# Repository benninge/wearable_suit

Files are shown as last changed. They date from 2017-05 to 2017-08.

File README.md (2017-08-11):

# Smart dancing suit

The smart dancing suit project was part of the [Wearable Computing Systems Lab Course](https://es.informatik.uni-freiburg.de/teaching/wearable-lab) during the summer semester of 2017. The idea is to develop an LED covered dancing suit which generates a light show according to the current music and movements of the wearer, instead of running a predefined choreography like it is done in other approaches. This is what makes the suit a “smart" dancing suit.

Therefore the suit is equipped with a couple of sensors, which enable sensing of motions and sound. For the sound measurement, a microphone module is used. The measurement samples are then used to calculate the sound level or to apply a Fourier transform. The music spectrum can be shown on the chest display.
The motion measurements are performed by inertial measurement units (IMUs) which are mounted on hands and feet. This allows movement detection of individual body parts.

## Contents

* [System architecture](https://github.com/benninge/wearable_suit/blob/master/README.md#hardware-architecture)
    * [Mainboard](https://github.com/benninge/wearable_suit/blob/master/README.md#mainboard)
    * [Sensor Board](https://github.com/benninge/wearable_suit/blob/master/README.md#sensor-board)
* [Software](https://github.com/benninge/wearable_suit/blob/master/README.md#software)
    * [Mainboard firmware](https://github.com/benninge/wearable_suit/blob/master/README.md#mainboard-firmware)
    * [Sensor board firmware](https://github.com/benninge/wearable_suit/blob/master/README.md#sensor-board-firmware)
    * [App](https://github.com/benninge/wearable_suit/blob/master/README.md#app)

## Hardware architecture

The system is built according to the hardware architecture given in figure 1. The centerpiece of the system is the mainboard. It contains an STM32 microcontroller, which controls all the other modules. It is connected to the IMU sensor modules over a bus systems and it directly controls all LEDs as well as the microphone module, which is used for music detection. A bluetooth connection to an Android app was also planned, but is currently not implemented.

<figure role="group">
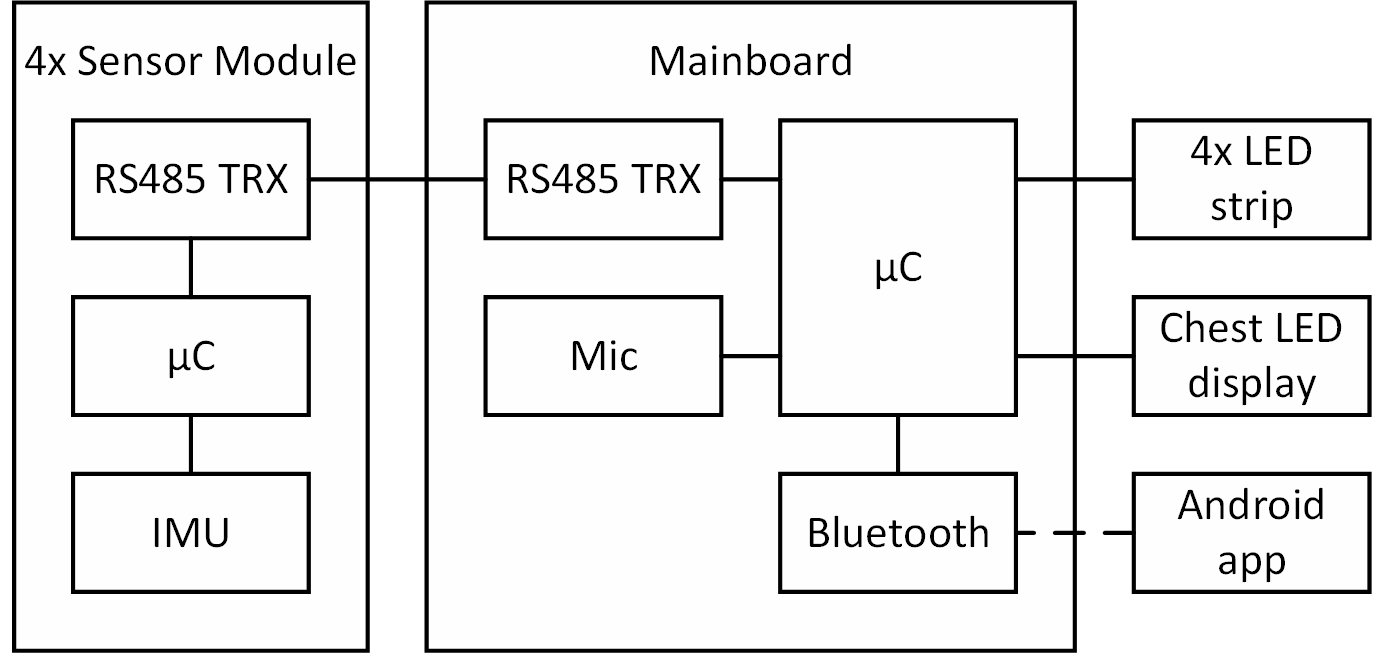
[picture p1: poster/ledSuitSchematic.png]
 
<div align="center"><figcaption> Figure 1: Schematic setup of the system </figcaption></div> 
</figure>

### Mainboard

The mainboard consists of an STM32F411E discovery board with a breadboard shield. The shield powers the discovery board and connects it to the sensor boards, the WS2812 RGB LED strips on arms and legs, the 10 x 10 LED display on the chest and the Adafruit MAX9814 microphone module. A wiring diagram of the mainboard shield is shown in figure 2.

<figure role="group">
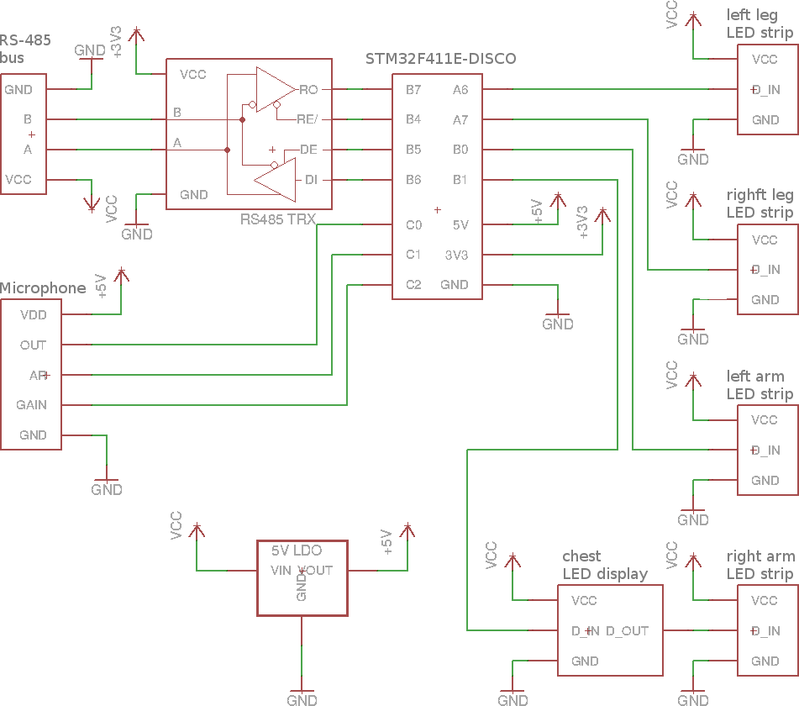
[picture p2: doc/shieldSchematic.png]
 
<div align="center"><figcaption> Figure 2: Wiring diagram of the mainboard shield </figcaption></div> 
</figure>

The sensor boards are connected over an RS-485 based bus system. The RS-485 transceiver should be a model with a 3.3V logic level. The chest display and the LED strips have to be connected according to the defines in the header files WS2812.h, ledSuit.h and the source file ledSuit.c of the mainboard firmware (which may be configured according to the used led-strip lengths). Since the LED strips are powered with 5V, each LED strip uses a switching regulator to generate its supply voltage out of the 3s LiPo power supply (which is called VCC here).

### Sensor board

The sensor module is an Arduino compatible custom circuit board. Figure 3 shows an assembled sensor board. The EAGLE files can be found in the "SensorBoard" folder in this repository. The sensor board hardware uses an ATmega328P microcontroller and a MPU-9250 IMU. It is directly powered by the 3s LiPo power supply and connected to the mainboard over the RS-485 bus.

<figure role="group">
 
<div align="center"><figcaption> Figure 3: Sensor board </figcaption></div> 
</figure>

## Software

This project provides a software development kit for the mainboard containing examples. Additionally, a sensor board firmware is provided as well as an incomplete Android app to control the suit with a smartphone.

### Mainboard firmware

The mainboard firmware can be found in the "mainboard" folder. It contains all libraries for developing your own project as well as some example programs which show the capabilities of the provided libraries.

#### Libraries

The module structure of the mainboard firmware is shown in figure 4. The used hardware modules are colored in blue and the libraries are colored in green. The whole suit functionality can easily be accessed through high level functions, provided by the software development kit libraries. The example program libraries show how the software development kit can be used, to program specific applications.

<figure role="group">
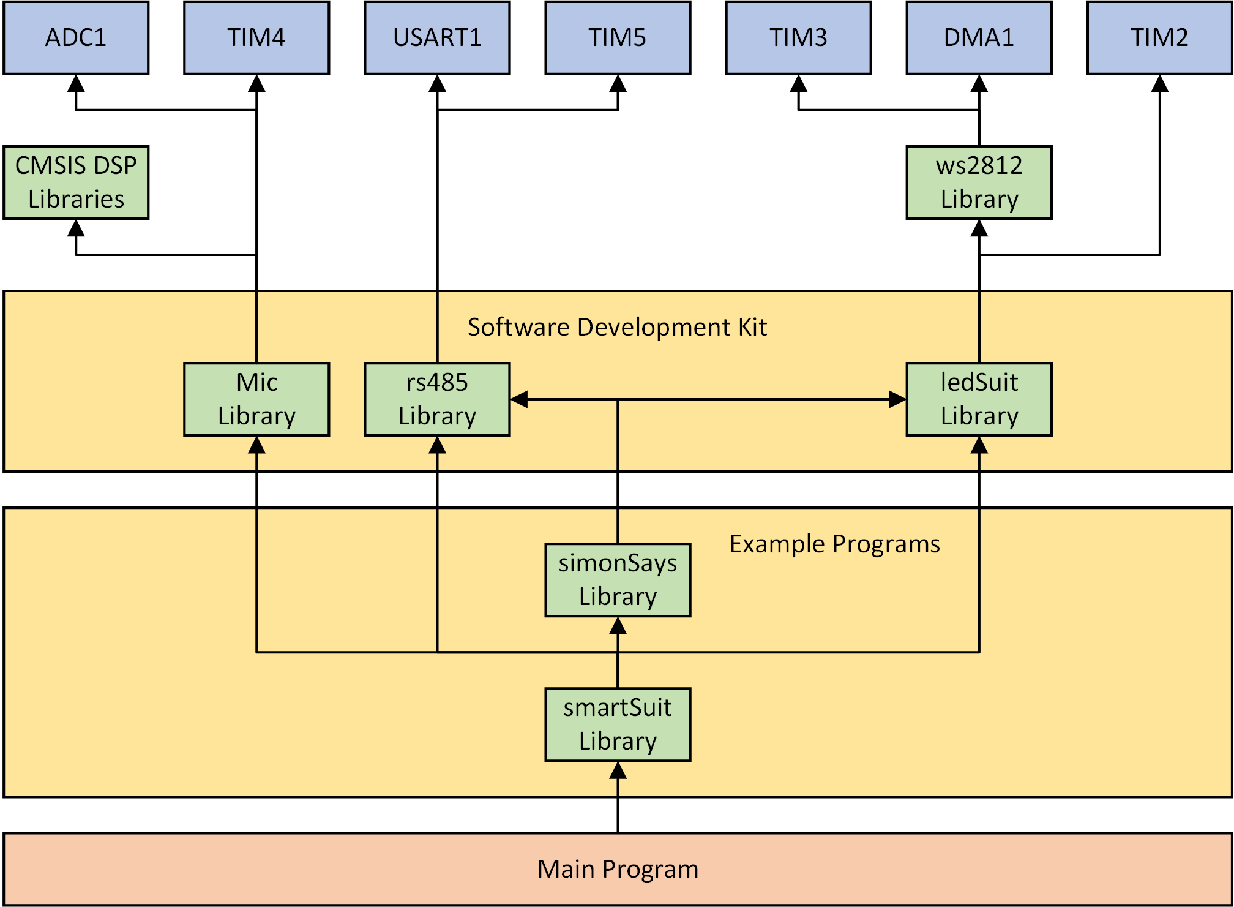
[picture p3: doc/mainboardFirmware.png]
 
<div align="center"><figcaption> Figure 4: Module structure of the mainboard firmware </figcaption></div> 
</figure>

#### Examples

The smartSuit library offers some example programs which show the capabilities of the software development kit. The examples are directly called in the main function and can be chosen by passing a different demo number to the smartSuit_demo function :
```c
void smartSuit_demo(int demoNumber);
```
The following demos are available:

1. Music spectrum and color fade auto rotate demo: Shows the music spectrum on the chest display and an automatically rotating color fade on arms and legs.
2. Sound level and moving demo: Lights up moving body parts with an automatically rotating color fade. The suit brightness depends on the sound level.
3. Music spectrum and strobe moving demo: Shows the music spectrum on the chest display and lights up moving body parts with a strobe.
4. Moving and auto color fade demo: Fades the color of the whole Suit and lights up moving body parts.
5. Pulse and smiley demo: Shows moving pulses on arms and legs and a smiley on the chest display.
6. Play Simon says: An implementation of the game "Simon says". The suit displays body movements, which the wearer has to reproduce.

### Sensor board firmware

Before flashing the firmware to the sensor boards, the Arduino bootloader needs to be flashed to the sensor boards according to the [Arduino ISP instructions](https://www.arduino.cc/en/Tutorial/ArduinoISP). The sensor board firmware can be found in the "arduino/src/mpu9250_basicDMP" folder.

The Digital Motion Processor (DMP) on the IMU of each sensor board performs 6-axis sensor fusion (ignoring the integrated magnetometer and barometer) using the [motion driver library](http://www.digikey.de/en/pdf/i/invensense/motion-driver-6-1-user-guide) of Invensense. The resulting quaternions and acceleration values are transmitted over I^2C to the ATmega328P microcontroller 100 times per second. The microcontroller then converts the quaternions into the Euler coordinate system and normalizes the acceleration values into multiples of g = 9.81 m/s^2. 9-axis fusion is possible using the MPU9250, but would result in a slower update rate and additional need to calibrate the magnetometer each time the suit is powered up.

A master-slave communication over RS485 is used to communicate these values from each sensor board to the mainboard. The master (mainboard) requests new sensor values of one slave (sensor board) at a time. This avoids possible packet collisions on the bus. To differentiate the sensor boards from each other, the SLAVE_ID in mpu9250_basicDMP.ino has to be set to a value between 1 and 4 which represents the sensor boards specific ID. Once a sensor board receives a request for new values, it checks if the request was meant for its SLAVE_ID. If that is the case, it sends back a package with the current yaw, pitch, roll, the current rates at which these values change, and the 3-axis acceleration values.

The following values for SLAVE_ID are used:
* SLAVE_ID = 1: left arm
* SLAVE_ID = 2: right arm
* SLAVE_ID = 3: left leg
* SLAVE_ID = 4: right leg

### App

The "App" folder contains the app source code. The app is programmed with Android Studio and therefore available for Android devices. With the help of the "Dancing Suit" app, the user can select features for the suit. The app runs on a smartphone but cannot connect to the suit yet, because the Bluetooth communication to the mainboard is not fully implemented.

The app starts with a splash screen. From the main activity the user can connect the suit to the Bluetooth module and slide in a navigation drawer. It contains the navigation destinations "Right Arm", "Left Arm", "Right Leg", "Left Leg", "Suit", "Demo", "Info" and "Share". A screenshot of the navigation drawer is shown in figure 5 (left). The user can control each body part separately, set settings for the hole suit, get information about the developer and find the share link for github.

In the activity COLOR, which is shown in figure 5 (middle), the settings for colors can be set. The checkboxes allow the user to select the colors. Furthermore, there are activities for the COLORFADE function and the AUTOCOLORFADE function. To get an overview about the functions and what they do, check out the header file "ledSuit.h" in the mainboard firmware. For each of the three activities, there is a spinner to choose the blinking pattern of the suit. Figure 5 (right) shows the contents in a pop-up dialog.

<figure role="group">
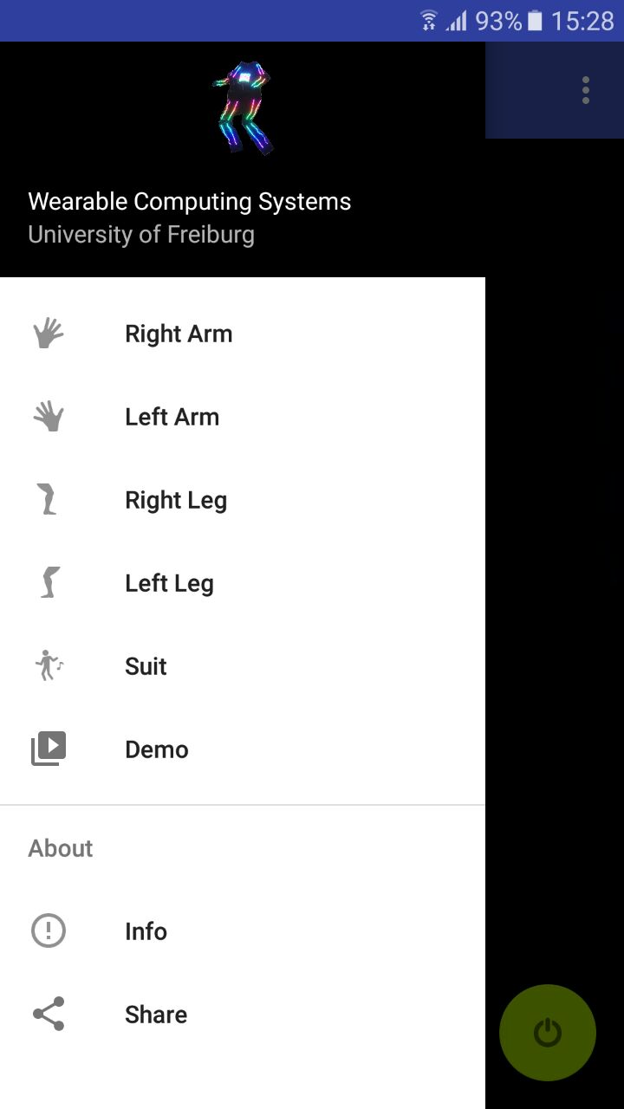
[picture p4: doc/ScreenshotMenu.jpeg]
<div align="center">
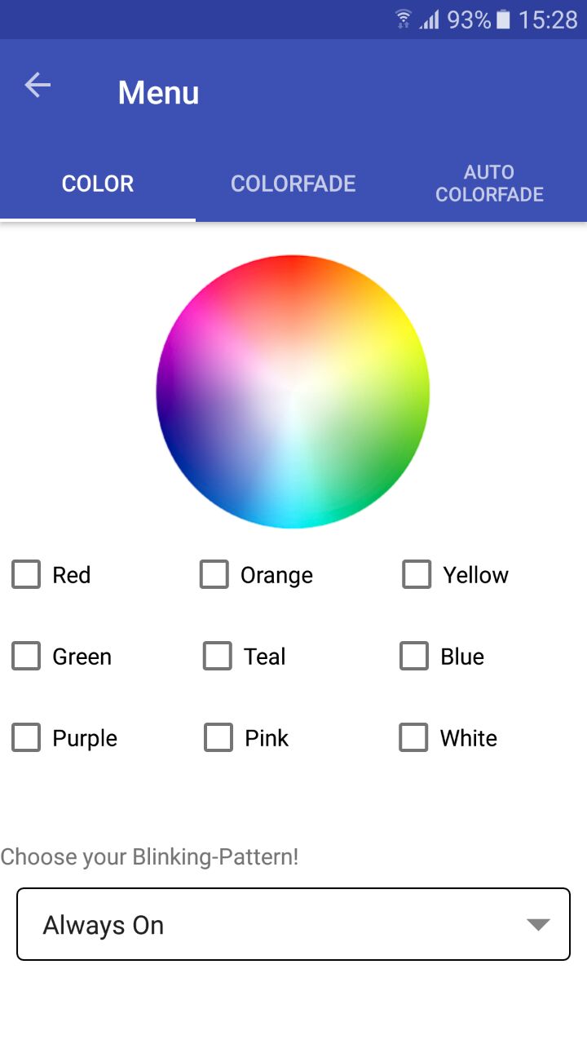
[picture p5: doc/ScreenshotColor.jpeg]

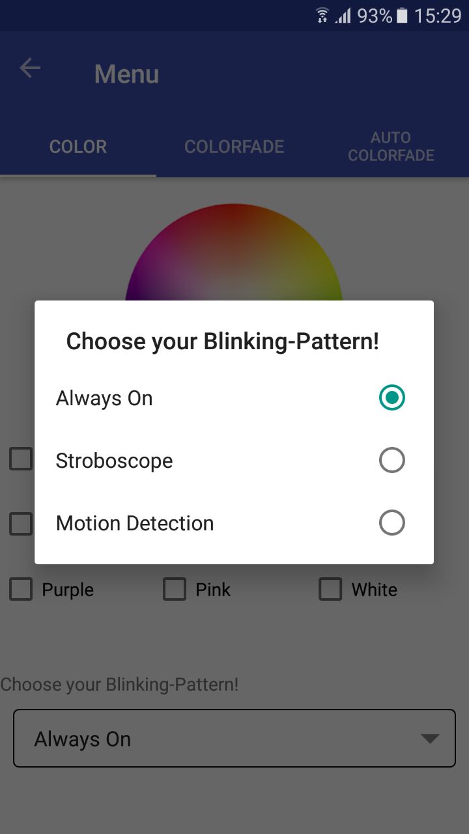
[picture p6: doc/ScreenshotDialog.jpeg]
</div> 
<div align="center"><figcaption> Figure 5: Navigation drawer of the Dancing Suit app (left), activity for color settings (middle) and spinner dialog for blinking pattern (right)</figcaption></div> 
</figure>

To implement the wireless data exchange the Android Bluetooth APIs are used. Following the guide from 
[Android Developers](https://developer.android.com/guide/topics/connectivity/bluetooth.html), scanning for Bluetooth devices and adapting to the module with an insert mac address works but there is no function for data transmission.

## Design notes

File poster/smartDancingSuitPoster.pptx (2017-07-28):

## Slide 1

Smart dancing suit

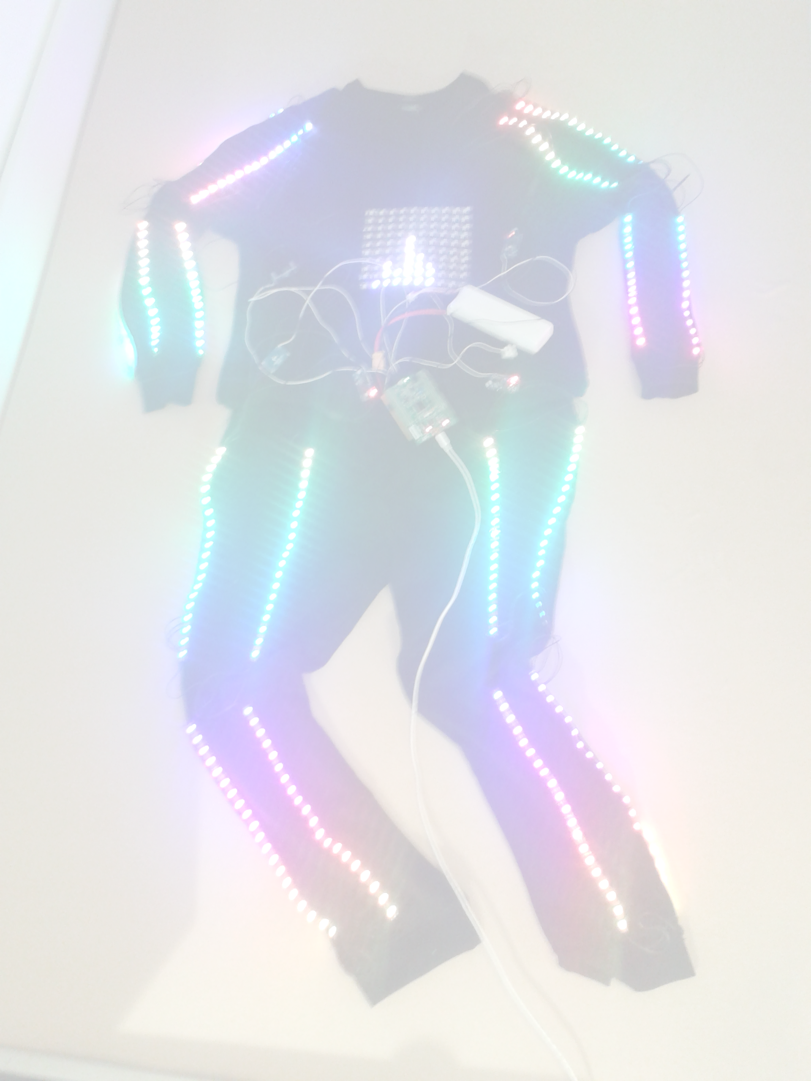
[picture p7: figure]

Making music visible

- The sound of the environment is measured by a microphone
- LEDs react to the environment sound
- Intelligent music recognition by applying fourier transform to the sound measurements
- Displaying of the music spectrum on chest

Reacting to movements

- Body movements are detected by IMUs mounted on hands and feet
- The IMUs perform 6-axis sensor fusion
- LEDs react to the movements measured by the IMUs

Creating an audiovisual performance

- LEDs change their colors and blinking patterns according to the music and the movements of the wearer
- Suit behavior can be configured via android app
- Generating an LED-choreography on the fly

TODO: fancy title

Schematc setup of the system

- Arduino-compatible custom sensor board hardware
- Yaw, pitch, roll and 3-axis acceleration data of each body part gets sent to the mainboard over an RS485 master-slave bus
- STM32F4 discovery board with breadboard shield as mainboard
- Individually addressable WS2812 RGB LEDs
- Sound detection with adafruit MAX9814 microphone module
- Communication with the android app via bluetooth
- TODO: Add some information about bluetooth communication and app

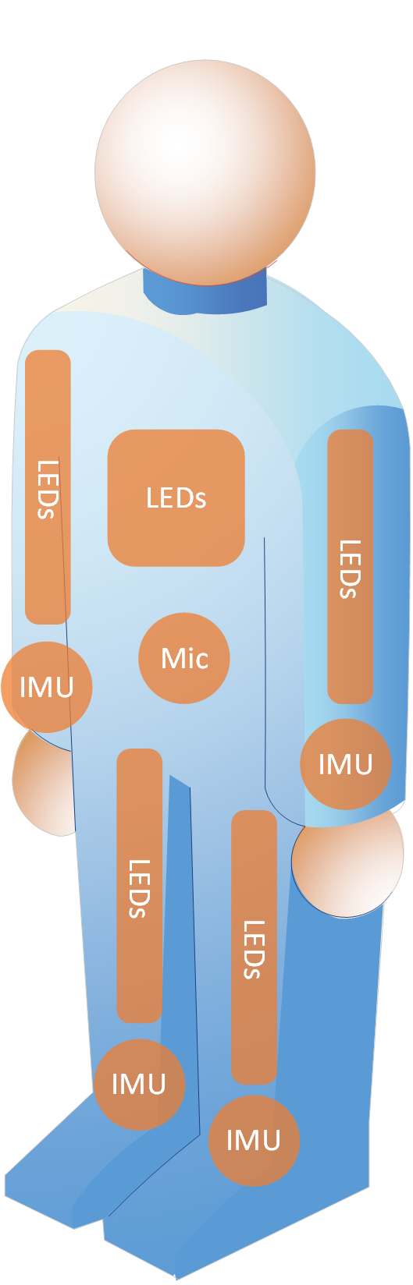
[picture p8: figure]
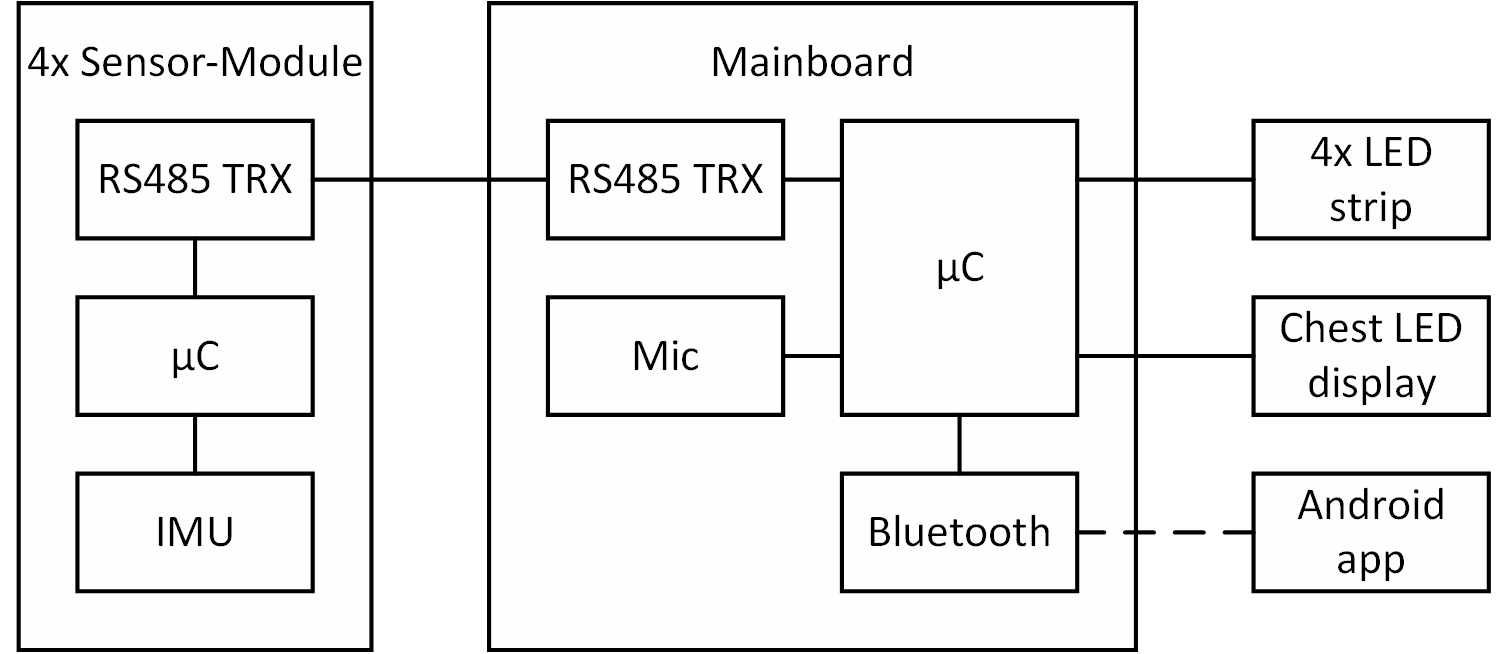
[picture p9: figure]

Positions of the sensors and LEDs on the suit

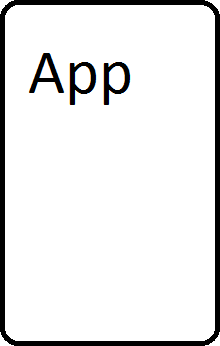
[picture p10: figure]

TODO: nice picture title (and a nice picture)

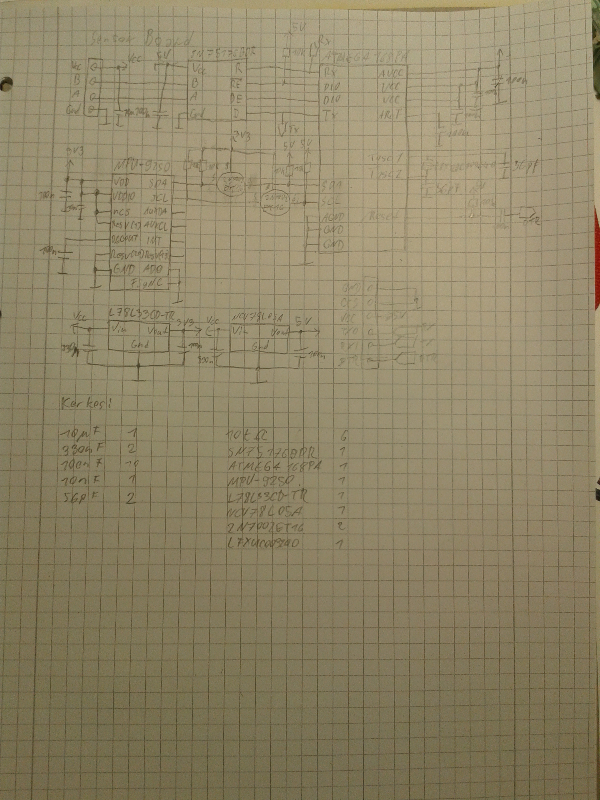
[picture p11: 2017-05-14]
SensorBoard/SensorBoardSchematic.jpg

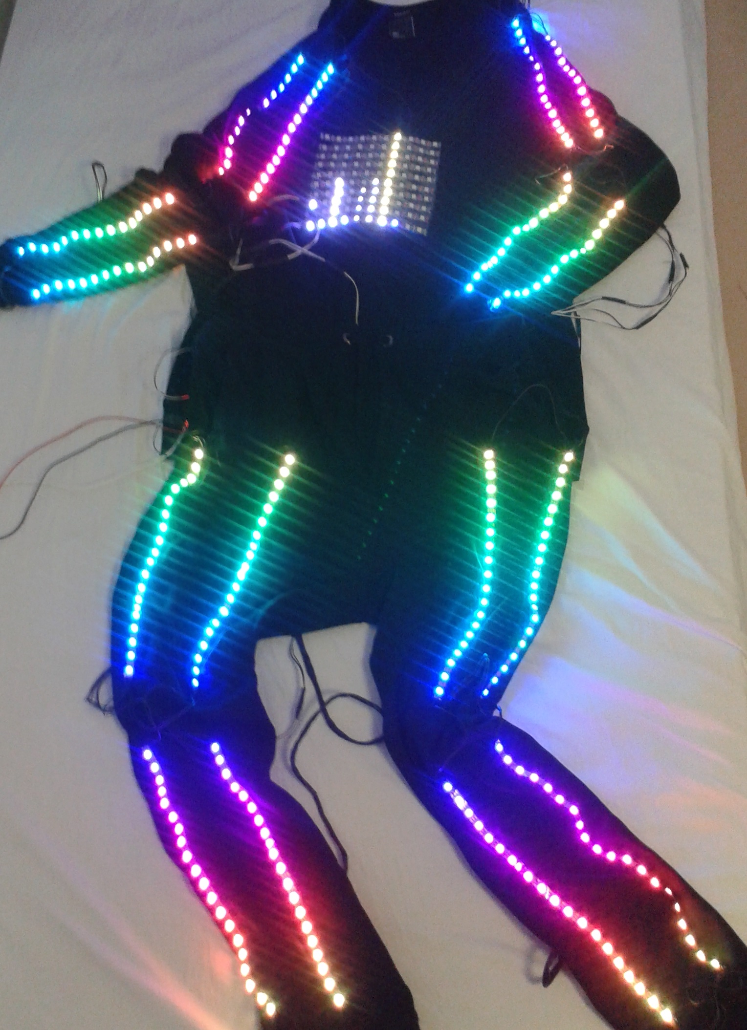
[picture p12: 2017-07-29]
poster/suit.jpg

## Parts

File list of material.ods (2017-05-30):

 | Part: | Comment: | Price per unit: | Vendor: | Quantity: | Total price: | Link:
Sensorboards | ATMEGA168PA-AU | Mikrocontroller | 1,64 | mouser | 4 | 6,56 | http://www.mouser.de/ProductDetail/Microchip-Technology-Atmel/ATMEGA168PA-AU/
 | LFXTAL003240Bulk | 16MHz Quarz | 0,17 | mouser | 4 | 0,68 | http://www.mouser.de/ProductDetail/IQD/LFXTAL003240Bulk/
 | SN75176BDR | RS485 Transceiver | 0,69 | mouser | 4 | 2,76 | http://www.mouser.de/ProductDetail/Texas-Instruments/SN75176BDR/
 | 2N7002ET1G | Mosfet | 0,13 | mouser | 8 | 1,04 | http://www.mouser.de/ProductDetail/ON-Semiconductor/2N7002ET1G/
 | L78L33CD-TR | voltage regulator | 0,33 | mouser | 4 | 1,32 | http://www.mouser.de/ProductDetail/STMicroelectronics/L78L33CD-TR/
 | NCV78L05ABDG | voltage regulator | 0,4 | mouser | 4 | 1,6 | http://www.mouser.de/ProductDetail/ON-Semiconductor/NCV78L05ABDG/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
 | 56pF 2% | smd ceramic capacitor | 0,09 | mouser | 8 | 0,72 | http://www.mouser.de/ProductDetail/Vishay-Vitramon/VJ0603A560GXAPW1BC/
 | 330nF | smd ceramic capacitor | 0,06 | mouser | 8 | 0,48 | http://www.mouser.de/ProductDetail/Yageo/CC0603KPX7R7BB334/
 | 10uF | smd ceramic capacitor | 0,14 | mouser | 4 | 0,56 | http://www.mouser.de/ProductDetail/AVX/0805YD106KAT4A/?qs=sGAEpiMZZMuMW9TJLBQkXmbDcqwIZ7kIWve9ZSNqR2w%3d
 |  |  |  |  |  | 0
Mainboard | OKR-T/30-W12-C | voltage regulator | 17,92 | mouser | 1 | 17,92 | http://www.mouser.de/ProductDetail/Murata/OKR-T-30-W12-C/
 | STM32F411E-DISCO | discovery board | 14,72 | mouser | 2 | 29,44 | http://www.mouser.de/ProductDetail/STMicroelectronics/STM32F411E-DISCO/
 | ws2812 5m black | 5m 300 LED strip | 28,65 | ebay | 2 | 57,3 | http://www.ebay.de/itm/1m-30-60-144-RGB-LED-Strip-Stripe-mit-WS2812B-5050-SMD-LEDs-WS2812-Versand-au-DE-/291800560383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
 |  |  |  |  |  | 0
Lab | HC06 | serial-bluetooth converter | 5,13 | ebay | 1 | 5,13 | http://www.ebay.de/itm/4-Pins-HC-06-RS232-Wireless-Serial-Bluetooth-RF-Transceiver-Module-fur-Arduino-/301703350188
 |  |  |  |  |  | 125,51

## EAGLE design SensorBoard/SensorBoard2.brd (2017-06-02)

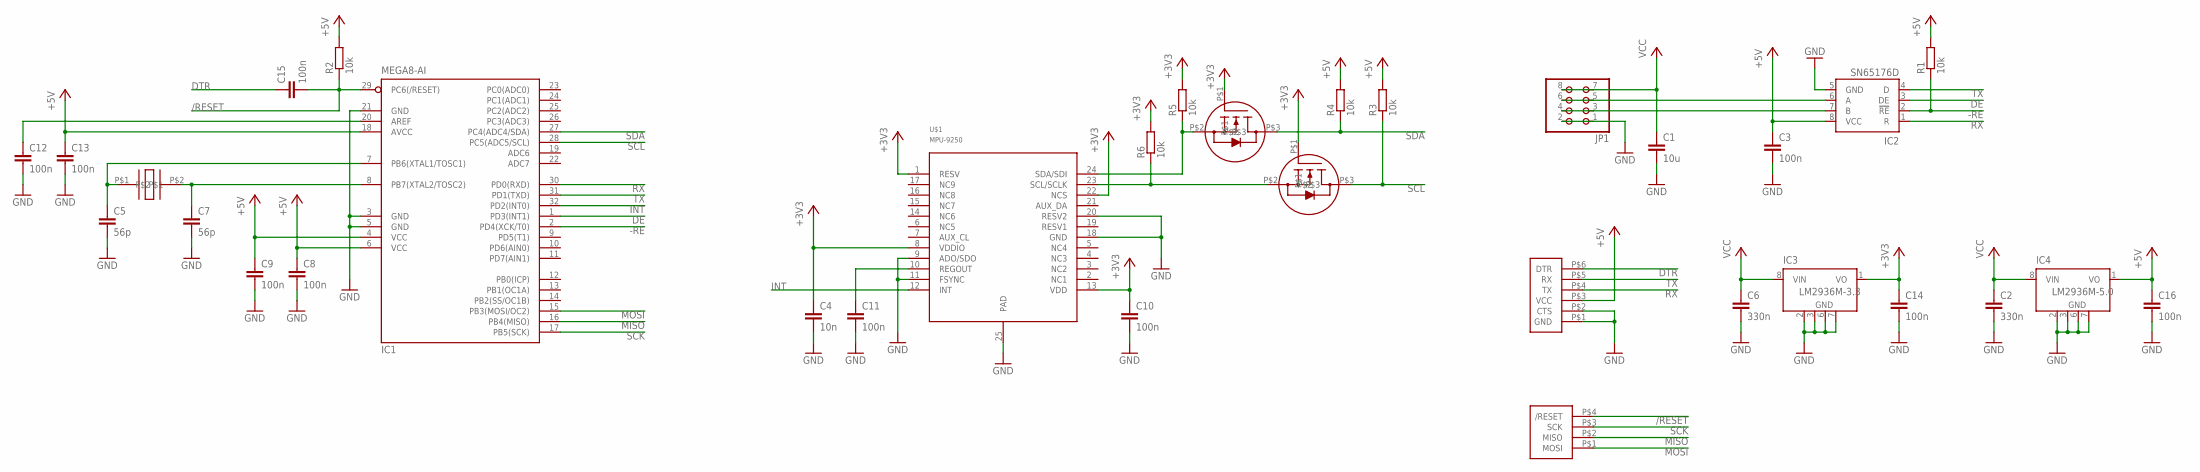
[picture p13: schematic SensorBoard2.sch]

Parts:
C1: 10u; C0805
C2, C6: 330n; C0603
C3, C8, C9, C10, C11, C12, C13, C14, C15, C16: 100n; C0603
C4: 10n; C0603
C5, C7: 56p; C0603
IC1: MEGA8-AI; TQFP32-08
IC2: SN65176D; SO-08
IC3: LM2936M-3.3; SO08
IC4: LM2936M-5.0; SO08
JP1: PINHD-2X4/90; 2X04/90
R1, R2, R3, R4, R5, R6: 10k; R0603
U$1: MPU-9250; LEAD-QFN24
U$2, U$3: 2N7002E; SOT-23-3
U$4: LFXTAL003240BULK
U$5: FTDI-PINHEADER
U$6: ISP_PADS

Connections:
+3V3: C4.1, C10.1, C14.1, IC3.1 (VO), R5.2, R6.2, U$1.1 (RESV), U$1.8 (VDDIO), U$1.13 (VDD), U$1.22 (NCS), U$2.P$1, U$3.P$1
+5V: C3.1, C8.1, C9.1, C13.1, C16.1, IC1.4 (VCC), IC1.6 (VCC), IC1.18 (AVCC), IC2.8 (VCC), IC4.1 (VO), R1.2, R2.2, R3.2, R4.2, U$5.P$3 (VCC)
-RE: IC1.2 (PD4(XCK/T0)), IC2.2 (!RE), R1.1
/RESET: C15.2, IC1.29 (PC6(/RESET)), R2.1, U$6.P$4 (/RESET)
DE: IC1.1 (PD3(INT1)), IC2.3 (DE)
DTR: C15.1, U$5.P$6 (DTR)
GND: C1.2, C2.2, C3.2, C4.2, C5.2, C6.2, C7.2, C8.2, C9.2, C10.2, C11.2, C12.2, C13.2, C14.2, C16.2, IC1.3 (GND), IC1.5 (GND), IC1.21 (GND), IC2.5 (GND), IC3.2 (GND), IC3.3 (GND), IC3.6 (GND), IC3.7 (GND), IC4.2 (GND), IC4.3 (GND), IC4.6 (GND), IC4.7 (GND), JP1.1, JP1.2, U$1.9 (ADO/SDO), U$1.11 (FSYNC), U$1.18 (GND), U$1.20 (RESV2), U$1.25 (PAD), U$5.P$1 (GND), U$5.P$2 (CTS)
INT: IC1.32 (PD2(INT0)), U$1.12 (INT)
MISO: IC1.16 (PB4(MISO)), U$6.P$2 (MISO)
MOSI: IC1.15 (PB3(MOSI/OC2)), U$6.P$1 (MOSI)
unnamed: IC2.6 (A), JP1.5, JP1.6
unnamed: IC2.7 (B), JP1.3, JP1.4
unnamed: R6.1, U$1.23 (SCL/SCLK), U$2.P$2
unnamed: C11.1, U$1.10 (REGOUT)
unnamed: C5.1, IC1.7 (PB6(XTAL1/TOSC1)), U$4.P$1
unnamed: R5.1, U$1.24 (SDA/SDI), U$3.P$2
unnamed: C7.1, IC1.8 (PB7(XTAL2/TOSC2)), U$4.P$2
unnamed: C12.1, IC1.20 (AREF)
RX: IC1.30 (PD0(RXD)), IC2.1 (R), U$5.P$4 (TX)
SCK: IC1.17 (PB5(SCK)), U$6.P$3 (SCK)
SCL: IC1.28 (PC5(ADC5/SCL)), R3.1, U$2.P$3
SDA: IC1.27 (PC4(ADC4/SDA)), R4.1, U$3.P$3
TX: IC1.31 (PD1(TXD)), IC2.4 (D), U$5.P$5 (RX)
VCC: C1.1, C2.1, C6.1, IC3.8 (VIN), IC4.8 (VIN), JP1.7, JP1.8

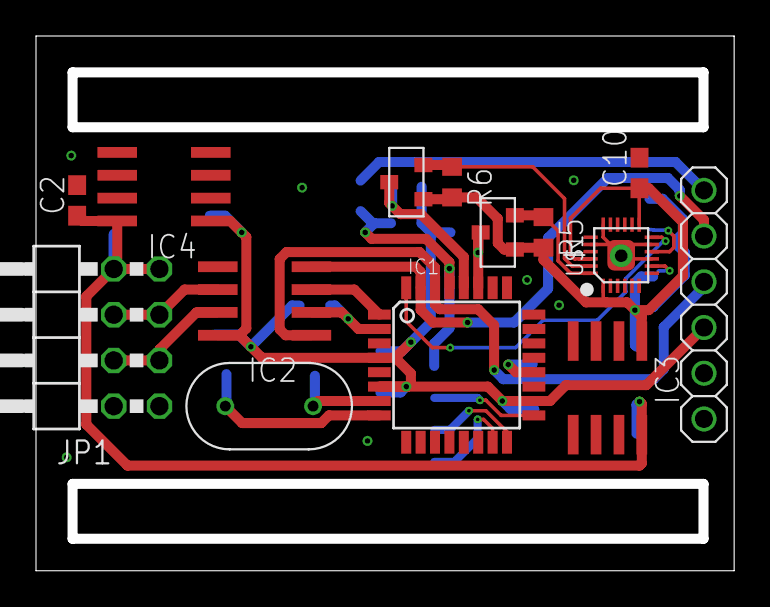
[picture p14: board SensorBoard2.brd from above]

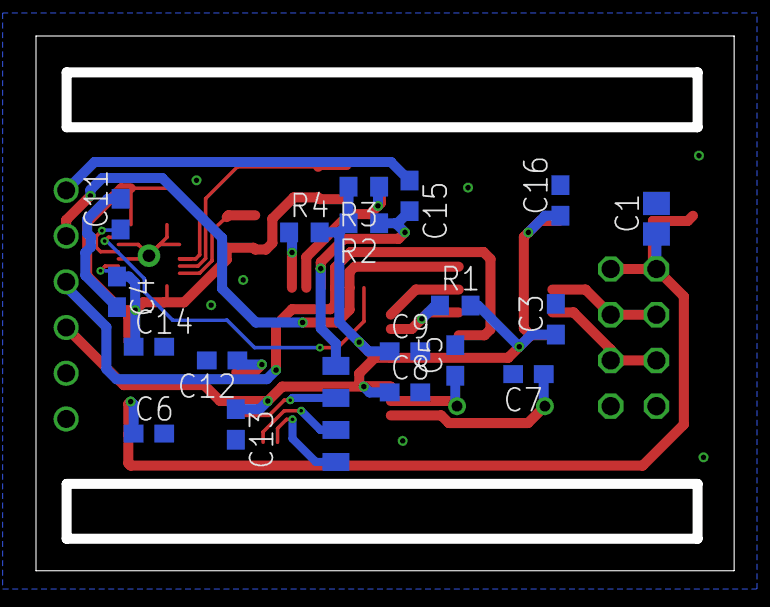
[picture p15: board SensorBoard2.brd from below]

Board: 2 copper layers, 38.8 x 29.7 mm, 33 parts (19 on the bottom side), 24 nets.

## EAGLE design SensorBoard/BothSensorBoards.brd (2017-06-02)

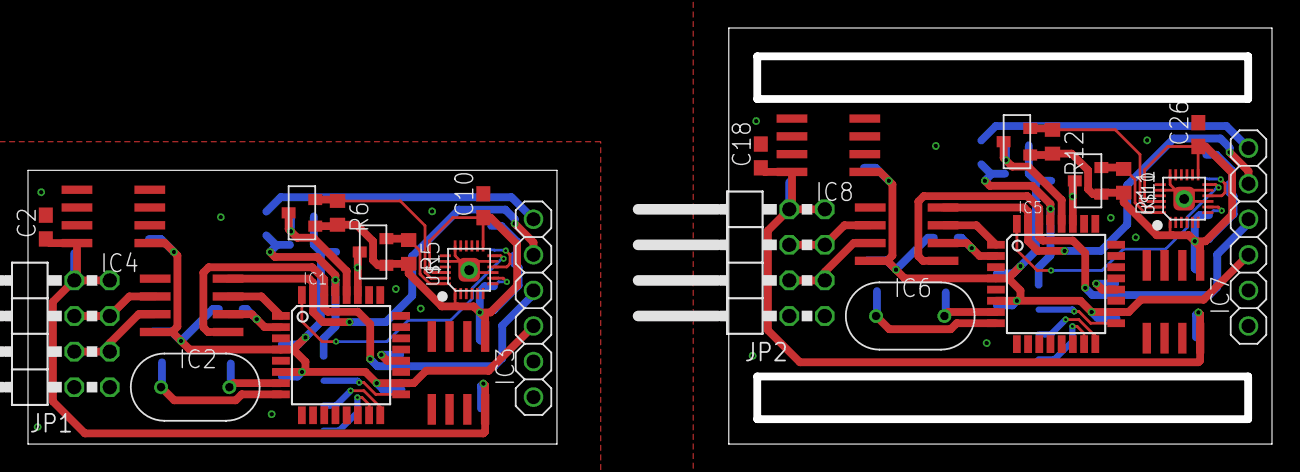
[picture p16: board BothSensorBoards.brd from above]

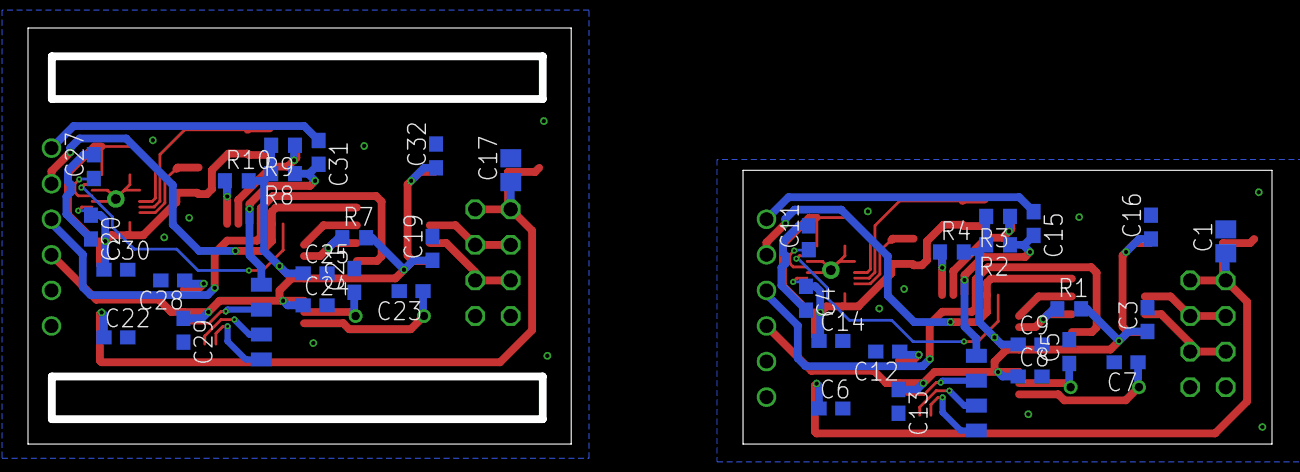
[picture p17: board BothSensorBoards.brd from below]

Board: 2 copper layers, 88.8 x 29.7 mm, 66 parts (38 on the bottom side), 48 nets.

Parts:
C1, C17: 10u; C0805
C2, C6, C18, C22: 330n; C0603
C3, C8, C9, C10, C11, C12, C13, C14, C15, C16, C19, C24, C25, C26, C27, C28, C29, C30, C31, C32: 100n; C0603
C4, C20: 10n; C0603
C5, C7, C21, C23: 56p; C0603
IC1, IC5: MEGA8-AI; TQFP32-08
IC2, IC6: SN65176D; SO-08
IC3, IC7: LM2936M-3.3; SO08
IC4, IC8: LM2936M-5.0; SO08
JP1, JP2: 2X04/90
R1, R2, R3, R4, R5, R6, R7, R8, R9, R10, R11, R12: 10k; R0603
U$1, U$10: MPU-9250; LEAD-QFN24
U$2, U$3, U$7, U$8: 2N7002E; SOT-23-3
U$4, U$9: LFXTAL003240BULK
U$5, U$11: FTDI-PINHEADER
U$6, U$12: ISP_PADS

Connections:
+3V1: C20.1, C26.1, C30.1, IC7.1, R11.2, R12.2, U$7.P$1, U$8.P$1, U$10.1, U$10.8, U$10.13, U$10.22
+3V3: C4.1, C10.1, C14.1, IC3.1, R5.2, R6.2, U$1.1, U$1.8, U$1.13, U$1.22, U$2.P$1, U$3.P$1
+5V: C3.1, C8.1, C9.1, C13.1, C16.1, IC1.4, IC1.6, IC1.18, IC2.8, IC4.1, R1.2, R2.2, R3.2, R4.2, U$5.P$3
+5V1: C19.1, C24.1, C25.1, C29.1, C32.1, IC5.4, IC5.6, IC5.18, IC6.8, IC8.1, R7.2, R8.2, R9.2, R10.2, U$11.P$3
-RE: IC1.2, IC2.2, R1.1
-RE1: IC5.2, IC6.2, R7.1
/RESET: C15.2, IC1.29, R2.1, U$6.P$4
/RESET1: C31.2, IC5.29, R8.1, U$12.P$4
DE: IC1.1, IC2.3
DE1: IC5.1, IC6.3
DTR: C15.1, U$5.P$6
DTR1: C31.1, U$11.P$6
GND: C1.2, C2.2, C3.2, C4.2, C5.2, C6.2, C7.2, C8.2, C9.2, C10.2, C11.2, C12.2, C13.2, C14.2, C16.2, IC1.3, IC1.5, IC1.21, IC2.5, IC3.2, IC3.3, IC3.6, IC3.7, IC4.2, IC4.3, IC4.6, IC4.7, JP1.1, JP1.2, U$1.9, U$1.11, U$1.18, U$1.20, U$1.25, U$5.P$1, U$5.P$2
GND1: C17.2, C18.2, C19.2, C20.2, C21.2, C22.2, C23.2, C24.2, C25.2, C26.2, C27.2, C28.2, C29.2, C30.2, C32.2, IC5.3, IC5.5, IC5.21, IC6.5, IC7.2, IC7.3, IC7.6, IC7.7, IC8.2, IC8.3, IC8.6, IC8.7, JP2.1, JP2.2, U$10.9, U$10.11, U$10.18, U$10.20, U$10.25, U$11.P$1, U$11.P$2
INT: IC1.32, U$1.12
INT1: IC5.32, U$10.12
MISO: IC1.16, U$6.P$2
MISO1: IC5.16, U$12.P$2
MOSI: IC1.15, U$6.P$1
MOSI1: IC5.15, U$12.P$1
unnamed: IC2.6, JP1.5, JP1.6
unnamed: IC2.7, JP1.3, JP1.4
unnamed: R6.1, U$1.23, U$2.P$2
unnamed: C11.1, U$1.10
unnamed: C5.1, IC1.7, U$4.P$1
unnamed: R5.1, U$1.24, U$3.P$2
unnamed: C7.1, IC1.8, U$4.P$2
unnamed: R12.1, U$7.P$2, U$10.23
unnamed: C12.1, IC1.20
unnamed: R11.1, U$8.P$2, U$10.24
unnamed: C27.1, U$10.10
unnamed: C21.1, IC5.7, U$9.P$1
unnamed: C23.1, IC5.8, U$9.P$2
unnamed: C28.1, IC5.20
unnamed: IC6.6, JP2.5, JP2.6
unnamed: IC6.7, JP2.3, JP2.4
RX: IC1.30, IC2.1, U$5.P$4
RX1: IC5.30, IC6.1, U$11.P$4
SCK: IC1.17, U$6.P$3
SCK1: IC5.17, U$12.P$3
SCL: IC1.28, R3.1, U$2.P$3
SCL1: IC5.28, R9.1, U$7.P$3
SDA: IC1.27, R4.1, U$3.P$3
SDA1: IC5.27, R10.1, U$8.P$3
TX: IC1.31, IC2.4, U$5.P$5
TX1: IC5.31, IC6.4, U$11.P$5
VCC: C1.1, C2.1, C6.1, IC3.8, IC4.8, JP1.7, JP1.8
VCC1: C17.1, C18.1, C22.1, IC7.8, IC8.8, JP2.7, JP2.8

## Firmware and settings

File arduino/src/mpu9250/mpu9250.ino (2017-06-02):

/* MPU9250 Basic Example Code
 by: Kris Winer
 date: April 1, 2014
 license: Beerware - Use this code however you'd like. If you
 find it useful you can buy me a beer some time.
 Modified by Brent Wilkins July 19, 2016

 Demonstrate basic MPU-9250 functionality including parameterizing the register
 addresses, initializing the sensor, getting properly scaled accelerometer,
 gyroscope, and magnetometer data out. Added display functions to allow display
 to on breadboard monitor. Addition of 9 DoF sensor fusion using open source
 Madgwick and Mahony filter algorithms. Sketch runs on the 3.3 V 8 MHz Pro Mini
 and the Teensy 3.1.

 SDA and SCL should have external pull-up resistors (to 3.3V).
 10k resistors are on the EMSENSR-9250 breakout board.

 Hardware setup:
 MPU9250 Breakout --------- Arduino
 VDD ---------------------- 3.3V
 VDDI --------------------- 3.3V
 SDA ----------------------- A4
 SCL ----------------------- A5
 GND ---------------------- GND
 */

#include "quaternionFilters.h"
#include "MPU9250.h"

#ifdef LCD
#include <Adafruit_GFX.h>
#include <Adafruit_PCD8544.h>

// Using NOKIA 5110 monochrome 84 x 48 pixel display
// pin 9 - Serial clock out (SCLK)
// pin 8 - Serial data out (DIN)
// pin 7 - Data/Command select (D/C)
// pin 5 - LCD chip select (CS)
// pin 6 - LCD reset (RST)
Adafruit_PCD8544 display = Adafruit_PCD8544(9, 8, 7, 5, 6);
#endif // LCD

#define AHRS true         // Set to false for basic data read
#define SerialDebug true  // Set to true to get Serial output for debugging

// Pin definitions
int intPin = 12;  // These can be changed, 2 and 3 are the Arduinos ext int pins
int myLed  = 13;  // Set up pin 13 led for toggling

MPU9250 myIMU;

void setup()
{
  Wire.begin();
  // TWBR = 12;  // 400 kbit/sec I2C speed
  Serial.begin(38400);

  // Set up the interrupt pin, its set as active high, push-pull
  pinMode(intPin, INPUT);
  digitalWrite(intPin, LOW);
  pinMode(myLed, OUTPUT);
  digitalWrite(myLed, HIGH);

  // Read the WHO_AM_I register, this is a good test of communication
  byte c = myIMU.readByte(MPU9250_ADDRESS, WHO_AM_I_MPU9250);
  Serial.print(F("MPU9250 I AM 0x"));
  Serial.print(c, HEX);
  Serial.print(F(" I should be 0x"));
  Serial.println(0x71, HEX);


  if (c == 0x71) // WHO_AM_I should always be 0x71
  {
    Serial.println(F("MPU9250 is online..."));

    // Start by performing self test and reporting values
    myIMU.MPU9250SelfTest(myIMU.selfTest);
    Serial.print(F("x-axis self test: acceleration trim within : "));
    Serial.print(myIMU.selfTest[0],1); Serial.println("% of factory value");
    Serial.print(F("y-axis self test: acceleration trim within : "));
    Serial.print(myIMU.selfTest[1],1); Serial.println("% of factory value");
    Serial.print(F("z-axis self test: acceleration trim within : "));
    Serial.print(myIMU.selfTest[2],1); Serial.println("% of factory value");
    Serial.print(F("x-axis self test: gyration trim within : "));
    Serial.print(myIMU.selfTest[3],1); Serial.println("% of factory value");
    Serial.print(F("y-axis self test: gyration trim within : "));
    Serial.print(myIMU.selfTest[4],1); Serial.println("% of factory value");
    Serial.print(F("z-axis self test: gyration trim within : "));
    Serial.print(myIMU.selfTest[5],1); Serial.println("% of factory value");

    // Calibrate gyro and accelerometers, load biases in bias registers
    myIMU.calibrateMPU9250(myIMU.gyroBias, myIMU.accelBias);

#ifdef LCD
    display.clearDisplay();

    display.setCursor(0, 0); display.print("MPU9250 bias");
    display.setCursor(0, 8); display.print(" x   y   z  ");

    display.setCursor(0,  16); display.print((int)(1000*myIMU.accelBias[0]));
    display.setCursor(24, 16); display.print((int)(1000*myIMU.accelBias[1]));
    display.setCursor(48, 16); display.print((int)(1000*myIMU.accelBias[2]));
    display.setCursor(72, 16); display.print("mg");

    display.setCursor(0,  24); display.print(myIMU.gyroBias[0], 1);
    display.setCursor(24, 24); display.print(myIMU.gyroBias[1], 1);
    display.setCursor(48, 24); display.print(myIMU.gyroBias[2], 1);
    display.setCursor(66, 24); display.print("o/s");

    display.display();
    delay(1000);
#endif // LCD

    myIMU.initMPU9250();
    // Initialize device for active mode read of acclerometer, gyroscope, and
    // temperature
    Serial.println("MPU9250 initialized for active data mode....");

    // Read the WHO_AM_I register of the magnetometer, this is a good test of
    // communication
    byte d = myIMU.readByte(AK8963_ADDRESS, WHO_AM_I_AK8963);
    Serial.print("AK8963 ");
    Serial.print("I AM 0x");
    Serial.print(d, HEX);
    Serial.print(" I should be 0x");
    Serial.println(0x48, HEX);

#ifdef LCD
    display.clearDisplay();
    display.setCursor(20,0); display.print("AK8963");
    display.setCursor(0,10); display.print("I AM");
    display.setCursor(0,20); display.print(d, HEX);
    display.setCursor(0,30); display.print("I Should Be");
    display.setCursor(0,40); display.print(0x48, HEX);
    display.display();
    delay(1000);
#endif // LCD

    if (d != 0x48)
    {
      // Communication failed, stop here
      Serial.println(F("Communication failed, abort!"));
      Serial.flush();
      //abort();
    }

    // Get magnetometer calibration from AK8963 ROM
    myIMU.initAK8963(myIMU.factoryMagCalibration);
    // Initialize device for active mode read of magnetometer
    Serial.println("AK8963 initialized for active data mode....");

    if (SerialDebug)
    {
      //  Serial.println("Calibration values: ");
      Serial.print("X-Axis factory sensitivity adjustment value ");
      Serial.println(myIMU.factoryMagCalibration[0], 2);
      Serial.print("Y-Axis factory sensitivity adjustment value ");
      Serial.println(myIMU.factoryMagCalibration[1], 2);
      Serial.print("Z-Axis factory sensitivity adjustment value ");
      Serial.println(myIMU.factoryMagCalibration[2], 2);
    }

#ifdef LCD
    display.clearDisplay();
    display.setCursor(20,0);  display.print("AK8963");
    display.setCursor(0,10);  display.print("ASAX ");
    display.setCursor(50,10); display.print(myIMU.factoryMagCalibration[0], 2);
    display.setCursor(0,20);  display.print("ASAY ");
    display.setCursor(50,20); display.print(myIMU.factoryMagCalibration[1], 2);
    display.setCursor(0,30);  display.print("ASAZ ");
    display.setCursor(50,30); display.print(myIMU.factoryMagCalibration[2], 2);
    display.display();
    delay(1000);
#endif // LCD

    // Get sensor resolutions, only need to do this once
    myIMU.getAres();
    myIMU.getGres();
    myIMU.getMres();

    // The next call delays for 4 seconds, and then records about 15 seconds of
    // data to calculate bias and scale.
    myIMU.magCalMPU9250(myIMU.magBias, myIMU.magScale);
    Serial.println("AK8963 mag biases (mG)");
    Serial.println(myIMU.magBias[0]);
    Serial.println(myIMU.magBias[1]);
    Serial.println(myIMU.magBias[2]);

    Serial.println("AK8963 mag scale (mG)");
    Serial.println(myIMU.magScale[0]);
    Serial.println(myIMU.magScale[1]);
    Serial.println(myIMU.magScale[2]);
    delay(2000); // Add delay to see results before serial spew of data

    if(SerialDebug)
    {
      Serial.println("Magnetometer:");
      Serial.print("X-Axis sensitivity adjustment value ");
      Serial.println(myIMU.factoryMagCalibration[0], 2);
      Serial.print("Y-Axis sensitivity adjustment value ");
      Serial.println(myIMU.factoryMagCalibration[1], 2);
      Serial.print("Z-Axis sensitivity adjustment value ");
      Serial.println(myIMU.factoryMagCalibration[2], 2);
    }

#ifdef LCD
    display.clearDisplay();
    display.setCursor(20,0); display.print("AK8963");
    display.setCursor(0,10); display.print("ASAX "); display.setCursor(50,10);
    display.print(myIMU.factoryMagCalibration[0], 2);
    display.setCursor(0,20); display.print("ASAY "); display.setCursor(50,20);
    display.print(myIMU.factoryMagCalibration[1], 2);
    display.setCursor(0,30); display.print("ASAZ "); display.setCursor(50,30);
    display.print(myIMU.factoryMagCalibration[2], 2);
    display.display();
    delay(1000);
#endif // LCD
  } // if (c == 0x71)
  else
  {
    Serial.print("Could not connect to MPU9250: 0x");
    Serial.println(c, HEX);

    // Communication failed, stop here
    Serial.println(F("Communication failed, abort!"));
    Serial.flush();
    abort();
  }
}

void loop()
{
  // If intPin goes high, all data registers have new data
  // On interrupt, check if data ready interrupt
  if (myIMU.readByte(MPU9250_ADDRESS, INT_STATUS) & 0x01)
  {
    myIMU.readAccelData(myIMU.accelCount);  // Read the x/y/z adc values

    // Now we'll calculate the accleration value into actual g's
    // This depends on scale being set
    myIMU.ax = (float)myIMU.accelCount[0] * myIMU.aRes; // - myIMU.accelBias[0];
    myIMU.ay = (float)myIMU.accelCount[1] * myIMU.aRes; // - myIMU.accelBias[1];
    myIMU.az = (float)myIMU.accelCount[2] * myIMU.aRes; // - myIMU.accelBias[2];

    myIMU.readGyroData(myIMU.gyroCount);  // Read the x/y/z adc values

    // Calculate the gyro value into actual degrees per second
    // This depends on scale being set
    myIMU.gx = (float)myIMU.gyroCount[0] * myIMU.gRes;
    myIMU.gy = (float)myIMU.gyroCount[1] * myIMU.gRes;
    myIMU.gz = (float)myIMU.gyroCount[2] * myIMU.gRes;

    myIMU.readMagData(myIMU.magCount);  // Read the x/y/z adc values

    // Calculate the magnetometer values in milliGauss
    // Include factory calibration per data sheet and user environmental
    // corrections
    // Get actual magnetometer value, this depends on scale being set
    myIMU.mx = (float)myIMU.magCount[0] * myIMU.mRes
               * myIMU.factoryMagCalibration[0] - myIMU.magBias[0];
    myIMU.my = (float)myIMU.magCount[1] * myIMU.mRes
               * myIMU.factoryMagCalibration[1] - myIMU.magBias[1];
    myIMU.mz = (float)myIMU.magCount[2] * myIMU.mRes
               * myIMU.factoryMagCalibration[2] - myIMU.magBias[2];
  } // if (readByte(MPU9250_ADDRESS, INT_STATUS) & 0x01)

  // Must be called before updating quaternions!
  myIMU.updateTime();

  // Sensors x (y)-axis of the accelerometer is aligned with the y (x)-axis of
  // the magnetometer; the magnetometer z-axis (+ down) is opposite to z-axis
  // (+ up) of accelerometer and gyro! We have to make some allowance for this
  // orientationmismatch in feeding the output to the quaternion filter. For the
  // MPU-9250, we have chosen a magnetic rotation that keeps the sensor forward
  // along the x-axis just like in the LSM9DS0 sensor. This rotation can be
  // modified to allow any convenient orientation convention. This is ok by
  // aircraft orientation standards! Pass gyro rate as rad/s
  MahonyQuaternionUpdate(myIMU.ax, myIMU.ay, myIMU.az, myIMU.gx * DEG_TO_RAD,
                         myIMU.gy * DEG_TO_RAD, myIMU.gz * DEG_TO_RAD, myIMU.my,
                         myIMU.mx, myIMU.mz, myIMU.deltat);

  if (!AHRS)
  {
    myIMU.delt_t = millis() - myIMU.count;
    if (myIMU.delt_t > 500)
    {
      if(SerialDebug)
      {
        // Print acceleration values in milligs!
        Serial.print("X-acceleration: "); Serial.print(1000 * myIMU.ax);
        Serial.print(" mg ");
        Serial.print("Y-acceleration: "); Serial.print(1000 * myIMU.ay);
        Serial.print(" mg ");
        Serial.print("Z-acceleration: "); Serial.print(1000 * myIMU.az);
        Serial.println(" mg ");

        // Print gyro values in degree/sec
        Serial.print("X-gyro rate: "); Serial.print(myIMU.gx, 3);
        Serial.print(" degrees/sec ");
        Serial.print("Y-gyro rate: "); Serial.print(myIMU.gy, 3);
        Serial.print(" degrees/sec ");
        Serial.print("Z-gyro rate: "); Serial.print(myIMU.gz, 3);
        Serial.println(" degrees/sec");

        // Print mag values in degree/sec
        Serial.print("X-mag field: "); Serial.print(myIMU.mx);
        Serial.print(" mG ");
        Serial.print("Y-mag field: "); Serial.print(myIMU.my);
        Serial.print(" mG ");
        Serial.print("Z-mag field: "); Serial.print(myIMU.mz);
        Serial.println(" mG");

        myIMU.tempCount = myIMU.readTempData();  // Read the adc values
        // Temperature in degrees Centigrade
        myIMU.temperature = ((float) myIMU.tempCount) / 333.87 + 21.0;
        // Print temperature in degrees Centigrade
        Serial.print("Temperature is ");  Serial.print(myIMU.temperature, 1);
        Serial.println(" degrees C");
      }

#ifdef LCD
      display.clearDisplay();
      display.setCursor(0, 0); display.print("MPU9250/AK8963");
      display.setCursor(0, 8); display.print(" x   y   z  ");

      display.setCursor(0,  16); display.print((int)(1000 * myIMU.ax));
      display.setCursor(24, 16); display.print((int)(1000 * myIMU.ay));
      display.setCursor(48, 16); display.print((int)(1000 * myIMU.az));
      display.setCursor(72, 16); display.print("mg");

      display.setCursor(0,  24); display.print((int)(myIMU.gx));
      display.setCursor(24, 24); display.print((int)(myIMU.gy));
      display.setCursor(48, 24); display.print((int)(myIMU.gz));
      display.setCursor(66, 24); display.print("o/s");

      display.setCursor(0,  32); display.print((int)(myIMU.mx));
      display.setCursor(24, 32); display.print((int)(myIMU.my));
      display.setCursor(48, 32); display.print((int)(myIMU.mz));
      display.setCursor(72, 32); display.print("mG");

      display.setCursor(0,  40); display.print("Gyro T ");
      display.setCursor(50,  40); display.print(myIMU.temperature, 1);
      display.print(" C");
      display.display();
#endif // LCD

      myIMU.count = millis();
      digitalWrite(myLed, !digitalRead(myLed));  // toggle led
    } // if (myIMU.delt_t > 500)
  } // if (!AHRS)
  else
  {
    // Serial print and/or display at 0.5 s rate independent of data rates
    myIMU.delt_t = millis() - myIMU.count;

    // update LCD once per half-second independent of read rate
    if (myIMU.delt_t > 500)
    {
      if(SerialDebug)
      {
        Serial.print("ax = ");  Serial.print((int)1000 * myIMU.ax);
        Serial.print(" ay = "); Serial.print((int)1000 * myIMU.ay);
        Serial.print(" az = "); Serial.print((int)1000 * myIMU.az);
        Serial.println(" mg");

        Serial.print("gx = ");  Serial.print(myIMU.gx, 2);
        Serial.print(" gy = "); Serial.print(myIMU.gy, 2);
        Serial.print(" gz = "); Serial.print(myIMU.gz, 2);
        Serial.println(" deg/s");

        Serial.print("mx = ");  Serial.print((int)myIMU.mx);
        Serial.print(" my = "); Serial.print((int)myIMU.my);
        Serial.print(" mz = "); Serial.print((int)myIMU.mz);
        Serial.println(" mG");

        Serial.print("q0 = ");  Serial.print(*getQ());
        Serial.print(" qx = "); Serial.print(*(getQ() + 1));
        Serial.print(" qy = "); Serial.print(*(getQ() + 2));
        Serial.print(" qz = "); Serial.println(*(getQ() + 3));
      }

// Define output variables from updated quaternion---these are Tait-Bryan
// angles, commonly used in aircraft orientation. In this coordinate system,
// the positive z-axis is down toward Earth. Yaw is the angle between Sensor
// x-axis and Earth magnetic North (or true North if corrected for local
// declination, looking down on the sensor positive yaw is counterclockwise.
// Pitch is angle between sensor x-axis and Earth ground plane, toward the
// Earth is positive, up toward the sky is negative. Roll is angle between
// sensor y-axis and Earth ground plane, y-axis up is positive roll. These
// arise from the definition of the homogeneous rotation matrix constructed
// from quaternions. Tait-Bryan angles as well as Euler angles are
// non-commutative; that is, the get the correct orientation the rotations
// must be applied in the correct order which for this configuration is yaw,
// pitch, and then roll.
// For more see
// http://en.wikipedia.org/wiki/Conversion_between_quaternions_and_Euler_angles
// which has additional links.
      myIMU.yaw   = atan2(2.0f * (*(getQ()+1) * *(getQ()+2) + *getQ()
                    * *(getQ()+3)), *getQ() * *getQ() + *(getQ()+1)
                    * *(getQ()+1) - *(getQ()+2) * *(getQ()+2) - *(getQ()+3)
                    * *(getQ()+3));
      myIMU.pitch = -asin(2.0f * (*(getQ()+1) * *(getQ()+3) - *getQ()
                    * *(getQ()+2)));
      myIMU.roll  = atan2(2.0f * (*getQ() * *(getQ()+1) + *(getQ()+2)
                    * *(getQ()+3)), *getQ() * *getQ() - *(getQ()+1)
                    * *(getQ()+1) - *(getQ()+2) * *(getQ()+2) + *(getQ()+3)
                    * *(getQ()+3));
      myIMU.pitch *= RAD_TO_DEG;
      myIMU.yaw   *= RAD_TO_DEG;

      // Declination of SparkFun Electronics (40°05'26.6"N 105°11'05.9"W) is
      // 	8° 30' E  ± 0° 21' (or 8.5°) on 2016-07-19
      // - http://www.ngdc.noaa.gov/geomag-web/#declination
      myIMU.yaw  -= 8.5;
      myIMU.roll *= RAD_TO_DEG;

      if(SerialDebug)
      {
        Serial.print("Yaw, Pitch, Roll: ");
        Serial.print(myIMU.yaw, 2);
        Serial.print(", ");
        Serial.print(myIMU.pitch, 2);
        Serial.print(", ");
        Serial.println(myIMU.roll, 2);

        Serial.print("rate = ");
        Serial.print((float)myIMU.sumCount / myIMU.sum, 2);
        Serial.println(" Hz");
      }

#ifdef LCD
      display.clearDisplay();

      display.setCursor(0, 0); display.print(" x   y   z  ");

      display.setCursor(0,  8); display.print((int)(1000 * myIMU.ax));
      display.setCursor(24, 8); display.print((int)(1000 * myIMU.ay));
      display.setCursor(48, 8); display.print((int)(1000 * myIMU.az));
      display.setCursor(72, 8); display.print("mg");

      display.setCursor(0,  16); display.print((int)(myIMU.gx));
      display.setCursor(24, 16); display.print((int)(myIMU.gy));
      display.setCursor(48, 16); display.print((int)(myIMU.gz));
      display.setCursor(66, 16); display.print("o/s");

      display.setCursor(0,  24); display.print((int)(myIMU.mx));
      display.setCursor(24, 24); display.print((int)(myIMU.my));
      display.setCursor(48, 24); display.print((int)(myIMU.mz));
      display.setCursor(72, 24); display.print("mG");

      display.setCursor(0,  32); display.print((int)(myIMU.yaw));
      display.setCursor(24, 32); display.print((int)(myIMU.pitch));
      display.setCursor(48, 32); display.print((int)(myIMU.roll));
      display.setCursor(66, 32); display.print("ypr");

    // With these settings the filter is updating at a ~145 Hz rate using the
    // Madgwick scheme and >200 Hz using the Mahony scheme even though the
    // display refreshes at only 2 Hz. The filter update rate is determined
    // mostly by the mathematical steps in the respective algorithms, the
    // processor speed (8 MHz for the 3.3V Pro Mini), and the magnetometer ODR:
    // an ODR of 10 Hz for the magnetometer produce the above rates, maximum
    // magnetometer ODR of 100 Hz produces filter update rates of 36 - 145 and
    // ~38 Hz for the Madgwick and Mahony schemes, respectively. This is
    // presumably because the magnetometer read takes longer than the gyro or
    // accelerometer reads. This filter update rate should be fast enough to
    // maintain accurate platform orientation for stabilization control of a
    // fast-moving robot or quadcopter. Compare to the update rate of 200 Hz
    // produced by the on-board Digital Motion Processor of Invensense's MPU6050
    // 6 DoF and MPU9150 9DoF sensors. The 3.3 V 8 MHz Pro Mini is doing pretty
    // well!
      display.setCursor(0, 40); display.print("rt: ");
      display.print((float) myIMU.sumCount / myIMU.sum, 2);
      display.print(" Hz");
      display.display();
#endif // LCD

      myIMU.count = millis();
      myIMU.sumCount = 0;
      myIMU.sum = 0;
    } // if (myIMU.delt_t > 500)
  } // if (AHRS)
}

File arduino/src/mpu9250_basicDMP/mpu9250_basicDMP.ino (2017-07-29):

#include "freeram.h"
#include "mpu.h"
#include "I2Cdev.h"
#include "RS485_protocol.h"

//#define DMP_DEBUG

const byte ENABLE_PIN = 3;
const byte RECEIVE_PIN = 4;
const byte SLAVE_ID = 4;
union float2bytes { float f; byte b[sizeof(float)]; };
float2bytes ypr0;
float2bytes ypr1;
float2bytes ypr2;
float2bytes gyro0;
float2bytes gyro1;
float2bytes gyro2;
float2bytes accel0;
float2bytes accel1;
float2bytes accel2;


void fWrite (const byte content)
  {
  Serial.write (content);
  }

int fAvailable ()
  {
  return Serial.available ();
  }

 int fRead ()
  {
  return Serial.read ();
  }


int ret;
void setup() {
    Fastwire::setup(400,0);
    Serial.begin(57600);
    ret = mympu_open(100);
    pinMode (ENABLE_PIN, OUTPUT);
    pinMode (RECEIVE_PIN, OUTPUT);// driver output enable
    digitalWrite (ENABLE_PIN, LOW);
    digitalWrite (RECEIVE_PIN, LOW);

#ifdef DMP_DEBUG
    Serial.print("MPU init: "); Serial.println(ret);
    Serial.print("Free mem: "); Serial.println(freeRam());
#endif
}

unsigned int c = 0; //cumulative number of successful MPU/DMP reads
unsigned int np = 0; //cumulative number of MPU/DMP reads that brought no packet back
unsigned int err_c = 0; //cumulative number of MPU/DMP reads that brought corrupted packet
unsigned int err_o = 0; //cumulative number of MPU/DMP reads that had overflow bit set

void loop() {
    ret = mympu_update(); // get new sensor data

    byte buffer [10];

    byte received = recvMsg (fAvailable, fRead, buffer, sizeof (buffer), 50);

      if (received != 0){

		  if (buffer [0] != SLAVE_ID)
			return;  // not me

		  if (buffer [1] != 0)
			return;  // sender not master


		  ypr0.f = mympu.ypr[0];
		  ypr1.f = mympu.ypr[1];
		  ypr2.f = mympu.ypr[2];
		  gyro0.f = mympu.gyro[0];
		  gyro1.f = mympu.gyro[1];
		  gyro2.f = mympu.gyro[2];
		  accel0.f = mympu.accel[0];
		  accel1.f = mympu.accel[1];
		  accel2.f = mympu.accel[2];

		  //delay (1);  // give the master a moment to prepare to receive

		  byte msg [] = {
			 0,  // send to master
			 SLAVE_ID, // sent from SLAVE_ID
			 ypr0.b[0],
			 ypr0.b[1],
			 ypr0.b[2],
			 ypr0.b[3],
			 ypr1.b[0],
			 ypr1.b[1],
			 ypr1.b[2],
			 ypr1.b[3],
			 ypr2.b[0],
			 ypr2.b[1],
			 ypr2.b[2],
			 ypr2.b[3],
			 gyro0.b[0],
			 gyro0.b[1],
			 gyro0.b[2],
			 gyro0.b[3],
			 gyro1.b[0],
			 gyro1.b[1],
			 gyro1.b[2],
			 gyro1.b[3],
			 gyro2.b[0],
			 gyro2.b[1],
			 gyro2.b[2],
			 gyro2.b[3],
			 accel0.b[0],
			 accel0.b[1],
			 accel0.b[2],
			 accel0.b[3],
			 accel1.b[0],
			 accel1.b[1],
			 accel1.b[2],
			 accel1.b[3],
			 accel2.b[0],
			 accel2.b[1],
			 accel2.b[2],
			 accel2.b[3],
		  };

		  digitalWrite (ENABLE_PIN, HIGH);  // enable sending
		  digitalWrite (RECEIVE_PIN, HIGH);  // enable sending
		  delay(1);
		  sendMsg (fWrite, msg, sizeof msg);
		  Serial.flush();
		  digitalWrite (ENABLE_PIN, LOW);  // disable sending
		  digitalWrite (RECEIVE_PIN, LOW);  // disable sending
		  //delay (100);

     }

#ifdef DMP_DEBUG
    switch (ret) {
	case 0: c++; break;
	case 1: np++; break;
	case 2: err_o++; break;
	case 3: err_c++; break;
	default:
		Serial.print("READ ERROR!  ");
		Serial.println(ret);
		break;;
    }

	    Serial.print(c); Serial.print(np); Serial.print("  "); Serial.print(err_c); Serial.print(" "); Serial.print(err_o);
	    Serial.print(" Y: "); Serial.print(mympu.ypr[0]);
	    Serial.print(" P: "); Serial.print(mympu.ypr[1]);
	    Serial.print(" R: "); Serial.print(mympu.ypr[2]);
	    Serial.print("\tgy: "); Serial.print(mympu.gyro[0]);
	    Serial.print(" gp: "); Serial.print(mympu.gyro[1]);
	    Serial.print(" gr: "); Serial.println(mympu.gyro[2]);
	    Serial.print(" a1: "); Serial.print(mympu.accel[0]);
	    Serial.print(" a2: "); Serial.print(mympu.accel[1]);
	    Serial.print(" a3: "); Serial.println(mympu.accel[2]);
#endif
}

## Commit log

2017-05-14 added list of material
    [list of material.ods]
2017-05-14 updated list of material
    [list of material.ods]
2017-05-14 added list of material and sensor board schematic
    [list of material.ods]
2017-05-20 change to serial1 for arduino leonardo
2017-05-30 added eagle files for sensor board
    [SensorBoard.sch]
2017-05-30 finished sensor board schematic
    [SensorBoard.sch]
2017-05-30 finished sensor board layout
    [SensorBoard.brd, SensorBoard.sch]
2017-05-31 made some non-functional changes on sensor board layout and schematic
    [SensorBoard.brd, SensorBoard.sch]
2017-06-02 added pads for flashing the bootloader to sensor board, added alternative version of sensor board
    [BothSensorBoards.brd, SensorBoard2.brd, SensorBoard2.sch]
2017-06-15 added accel values, bugfixes
    [mpu9250_basicDMP.ino]
2017-06-16 working prototype, pitch and roll flipped?
    [mpu9250_basicDMP.ino, rs485_master.ino]
2017-06-18 added empty mainboard firmware project
    [dancingSuitMainboardFirmware Debug.cfg]
2017-06-19 Added libraries for led strips and led suit to mainboard firmware
2017-06-21 fix project
    [wearableSuitMainboardFirmware Debug.cfg]
2017-06-22 replaced ws2811 library by own ws2812 library
    [main.c]
2017-06-22 added 4 channel support to ws2812 library, refactored ledSuit library
2017-06-22 added 4 channel support to ws2812 library, refactored ledSuit library (reverted from commit 1cc2ef613847d8b94c4e8f30ec4543500a34e13e)
    [main.c]
2017-06-22 added 4 channel support to ws2812 library, refactored ledSuit library (reverted from commit 1cc2ef613847d8b94c4e8f30ec4543500a34e13e) (reverted from commit d02fd2d8e26421906d317fddd71ffd60a5ddc54a)
    [main.c]
2017-06-22 added 4 channel support to ws2812 library, refactored ledSuit library (reverted from commit 1cc2ef613847d8b94c4e8f30ec4543500a34e13e) (reverted from commit d02fd2d8e26421906d317fddd71ffd60a5ddc54a) (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
    [main.c]
2017-06-23 Added a setBrightness function to ledSuit, did a bit of refactoring
2017-06-23 Added brightness and strobe functions to ledSuit library
2017-06-23 Added color fade, rotate and auto rotate functions to ledSuit library
2017-06-23 added stm32f4 data sheet and reference manual
2017-06-23 added interrupt code, not complete
2017-06-24 added functions for coloring individual leds, added shift functions, added auto color fade functions
2017-06-25 modified arduino code for test purposes, USART interrupt does not work
    [main.c, mpu9250_basicDMP.ino, rs485_slave.ino]
2017-06-27 refactored ledSuit library
2017-06-27 ledSuit library is now using timer 2 instead of system tick timer
2017-06-27 // Made some readability changes in ledSuit.h, Moved defines from ledSuit.c to ledSuit.h
2017-06-29 moved some defines from ledSuit.h to ledSuit.c
2017-06-30 minimal working rs485, ledsuit disabled
2017-07-02 reverted sensorboard code, added stm32 master slave requests for rs485, some occasional bad bits received?
    [main.c, mpu9250_basicDMP.ino]
2017-07-13 added basic chest display support to ledSuit library
2017-07-20 configured led suit and ws2812 libraries according to final hardware
2017-07-23 increased baud of sensor module
2017-07-25 modified led suits according to hardware changes
2017-07-26 changed sensorboard firmware to send actual imu values, switched mainboard usart from delay to timer interrupt triggered
2017-07-26 made some further changes according to hardware changes in led suit and ws2812 lib
2017-07-26 change to interrupt based sending over usart
2017-07-28 added a bit of sensor board info to poster
2017-07-28 added support to request and receive from up to 4 sensor boards
2017-07-29 moved update of sensor values from main to rx/tx interrupt
2017-07-30 added schematic files for last commit (modified poster again)
2017-08-04 added app
    [app_bar_main.xml]
2017-08-09 reademe WIP added shield schematic
    [mainboardShield.sch]
2017-08-09 added decription for sensor board firmware
